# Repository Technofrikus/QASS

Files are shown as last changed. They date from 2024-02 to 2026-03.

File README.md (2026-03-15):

# QASS

QAZ-like for a BAE (Big Ass Enter) and 10u spacebar (7u+8u)

QASS complete

More pictures and infos at [Moinboards](https://moinboards.de/projects/qass/).
[Buildguide](https://moinboards.de/guides/guide-qass/).

There are three versions: normal, lowbar (Miao for FAK-Firmware) and lowbar (Gemini for QMK/Vial). The normal version has the spacebar on the normal PCB. The lowbar uses the PCB as a plate on the bottom row and adds a lower PCB.

- Only the lowbar version was tested and fully finished. Please check the normal version before ordering.
- Lowbar:
  - v1.0 is tested and works with MIAO. XIAO would work as well but the pads on the underside I wanted to use are not GPIOs but only for a special serial protocol. So they cant be used.
  - v1.1 is Untested, but I only made cosmetic changes, so should still work fine.
  - Quark-Works made a fork and changed the MCU to a [Gemini](https://keeb.supply/products/0xcb-gemini) (rp2040 zero compatible). Thanks! You can find it [here](https://github.com/quark-works/QASS-Zero/tree/main).
  - v1.2 Used the fork by Quarks as a basis. Removed a little mistake and made some cosmetic changes.
  - v1.3 the prvious version works, but the silkscreen of the diodes is not visible (orientation of diodes). Corrected this and changed the direction of one diode to be more consistent with the other ones around it.

The latest version has the lower spacebar. Break off the lower part of the PCB and put it under the bottom row. Add headers at the connection points.

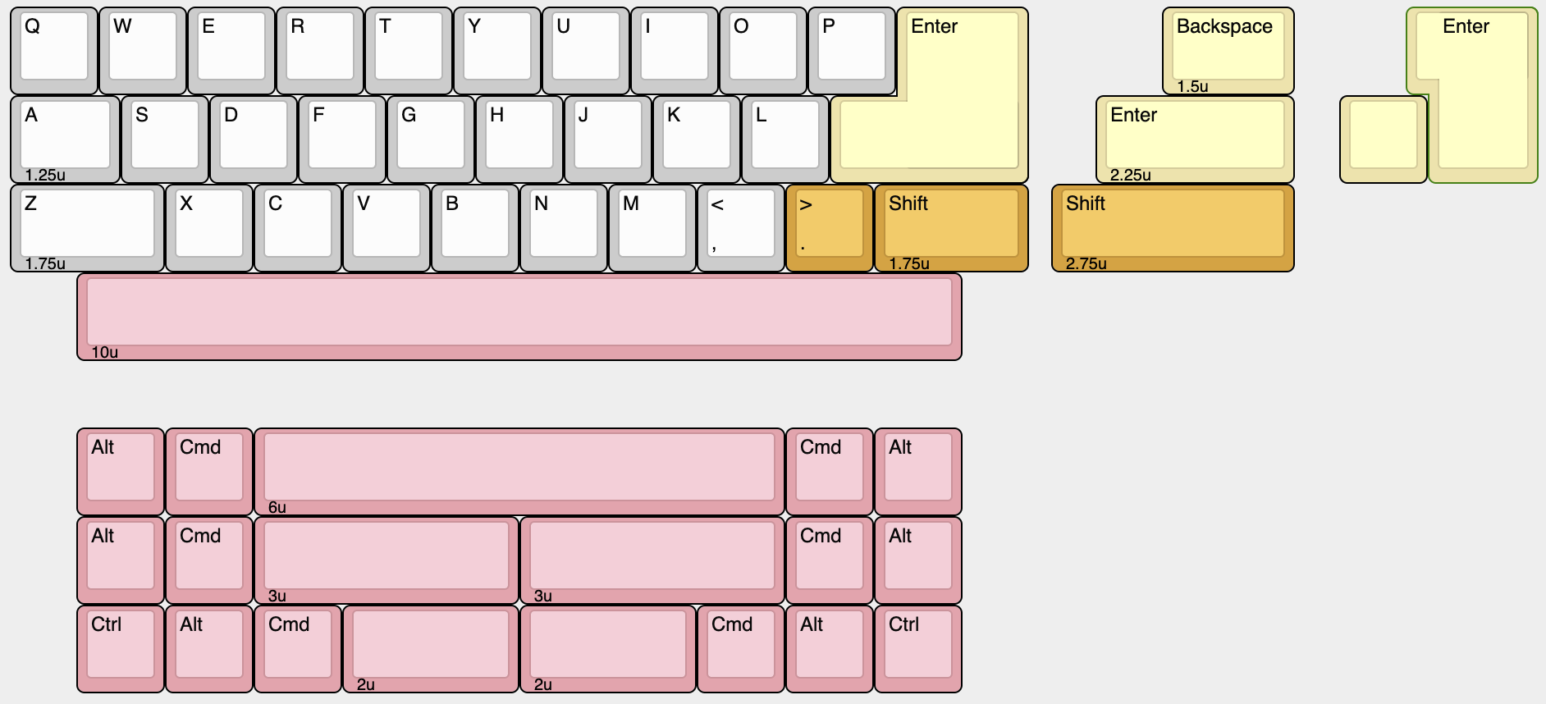
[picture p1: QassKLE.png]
QASS KLE

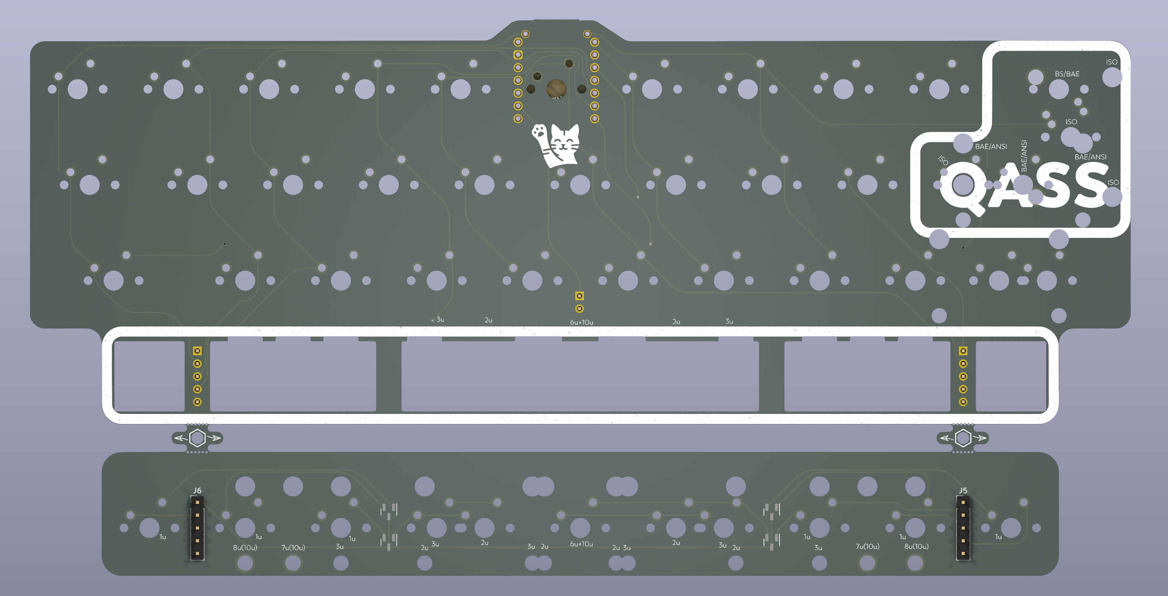
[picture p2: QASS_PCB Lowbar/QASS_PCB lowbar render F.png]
Front of PCB

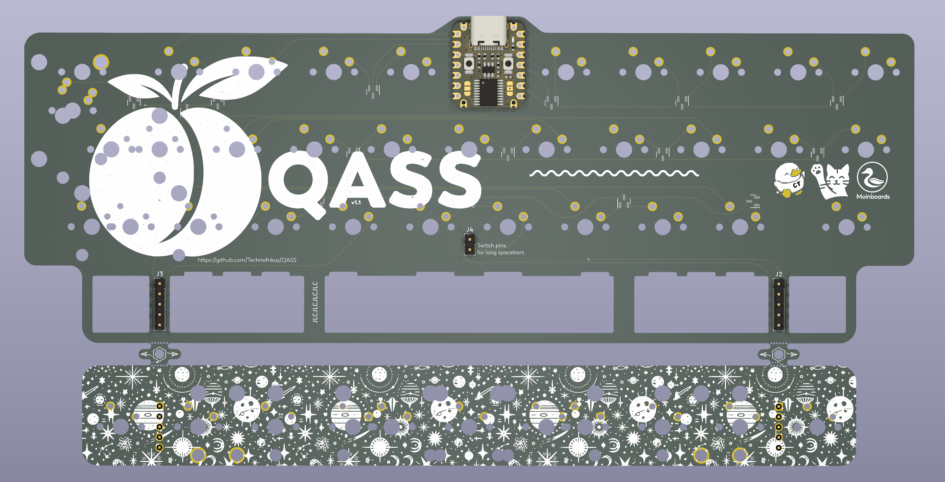
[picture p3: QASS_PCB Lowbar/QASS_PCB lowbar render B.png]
Back of PCB

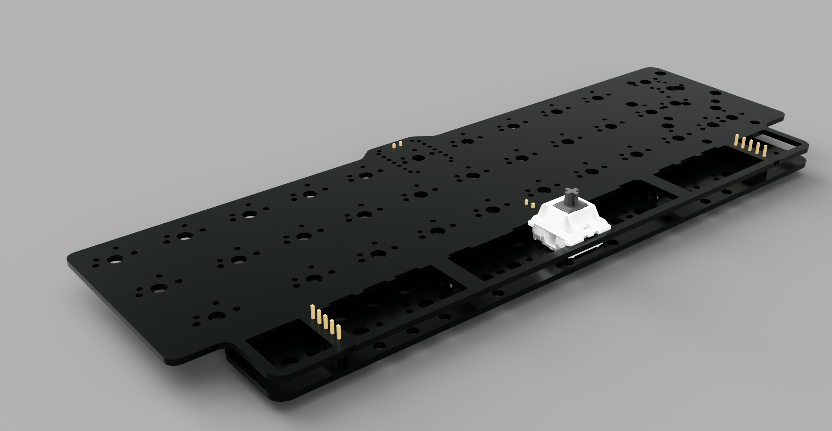
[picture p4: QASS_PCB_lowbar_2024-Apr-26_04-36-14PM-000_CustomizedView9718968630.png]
Lowbar PCB render


## Case

The 3D-printable case files are included now (March 2025).
Can recommend making the plate from metal. Gives the build more weight and looks nice. Tested with brass and copper. Use the special version to make sure they will not warp during cutting (havent tested it without these, just a precaution).
Print recommendations included, see txt file. 

It is for the low-bar version only.

## Firmware
- FAK config and info can be found on [moinboards](https://moinboards.de/guides/guide-qass/#firmware-and-flashing) and here in the firmware folder.
- Vial/Qmk for the fork by Quark. Confirmed working.

## BOM

- [Miao MCU](https://keeb.supply/products/miao) (or [Gemini](https://keeb.supply/products/0xcb-gemini), if you use the Gemini-PCB
- 3mm high hotswap headers (2.54mm pitch) and pins (the holes in the PCB are bigger than usual, so only the plastic part of the headers is on the PCB)
- 20x BAV70 diodes

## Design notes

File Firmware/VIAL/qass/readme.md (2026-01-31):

# qass

qass

*A short description of the keyboard/project*

* Keyboard Maintainer: [Moinboards](https://github.com/technofrikus)
* Hardware Supported: *The PCBs, controllers supported*
* Hardware Availability: *Links to where you can find this hardware*

Make example for this keyboard (after setting up your build environment):

    make qass:default

Flashing example for this keyboard:

    make qass:default:flash

See the [build environment setup](https://docs.qmk.fm/#/getting_started_build_tools) and the [make instructions](https://docs.qmk.fm/#/getting_started_make_guide) for more information. Brand new to QMK? Start with our [Complete Newbs Guide](https://docs.qmk.fm/#/newbs).

## Bootloader

Enter the bootloader in 3 ways:

* **Bootmagic reset**: Hold down the key at (0,0) in the matrix (usually the top left key or Escape) and plug in the keyboard
* **Physical reset button**: Briefly press the button on the back of the PCB - some may have pads you must short instead
* **Keycode in layout**: Press the key mapped to `QK_BOOT` if it is available

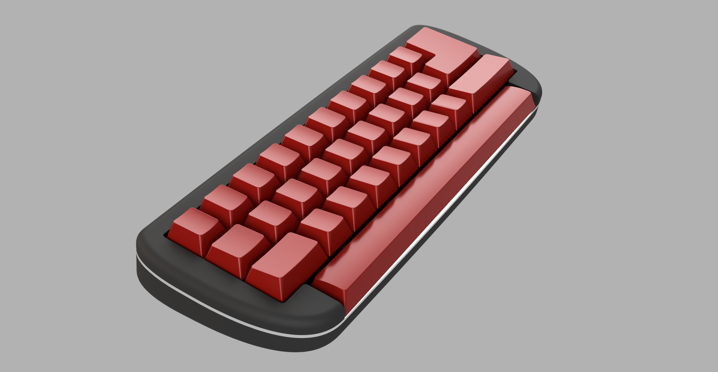
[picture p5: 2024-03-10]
QASS_2024-Mar-06_03-31-12PM-000_CustomizedView2353271758.png

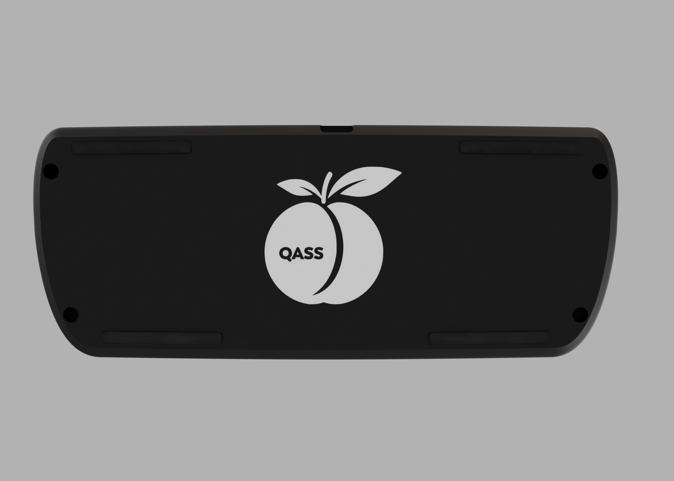
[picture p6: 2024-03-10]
QASS_2024-Mar-04_06-37-35PM-000_CustomizedView2128666624.png

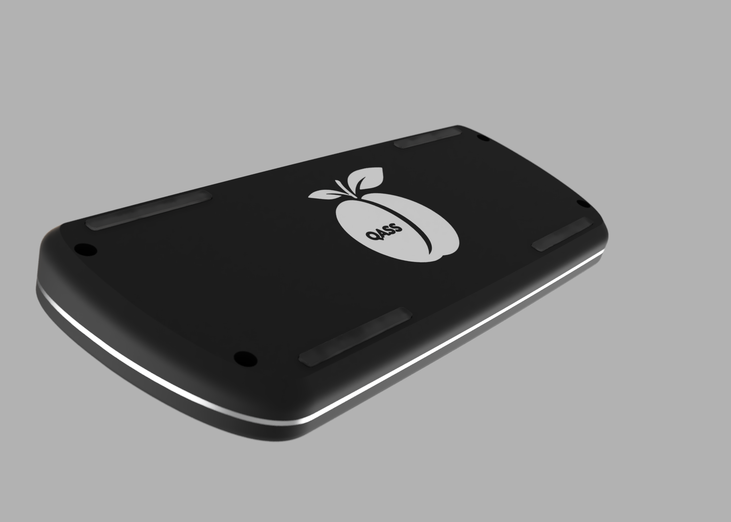
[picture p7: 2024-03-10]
QASS_2024-Mar-04_06-38-51PM-000_CustomizedView16006844155.png

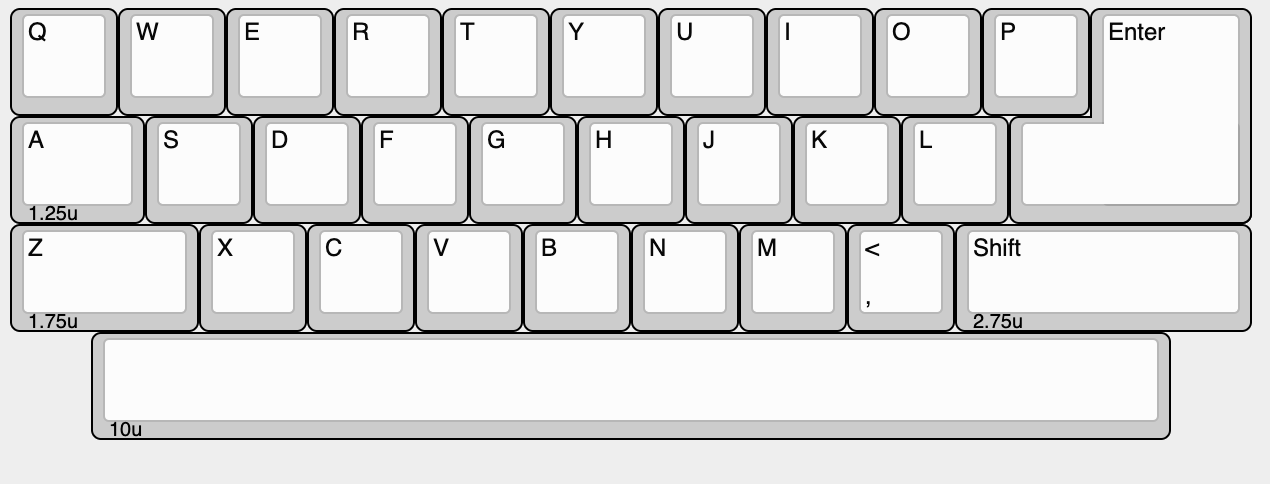
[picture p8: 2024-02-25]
Qass w 2.75 rshift.png

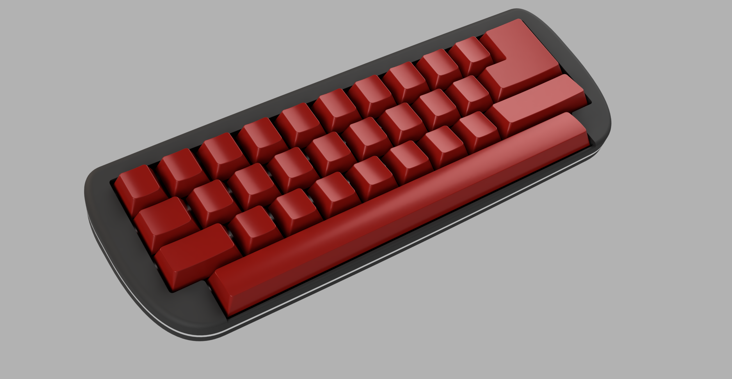
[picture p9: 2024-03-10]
QASS_2024-Mar-05_09-10-02PM-000_CustomizedView11185360985.png

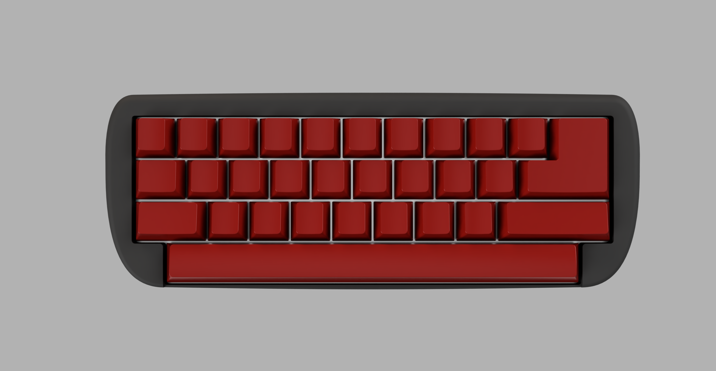
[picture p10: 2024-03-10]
QASS_2024-Mar-05_09-13-01PM-000_CustomizedView4947150229.png

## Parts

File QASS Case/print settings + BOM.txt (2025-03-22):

The stl includes all parts needed. Right click on it and split into parts. Move the plate and upper part away and group the bottom + logo. In OrcaSlicer this is done in the objects tab by marking all parts, right click and assemble.

The 3mf file are my print settings. Not sure if they work on your printer. Otherwise just import the stl.

Use two different colors for the logo and the rest.

I would recommend using variable layer height. The auto settings + smooth work fine. Otherwise the two faces touching the plate have big layer heights and it doesnt look as good.

Supports: bottom yes, other parts no

I use 3 perimeters, but 2 should work as well.

BOM:
- 4x M3x3 threaded insert
- 4x M3x10 srew
- 4x 5x50mm foot

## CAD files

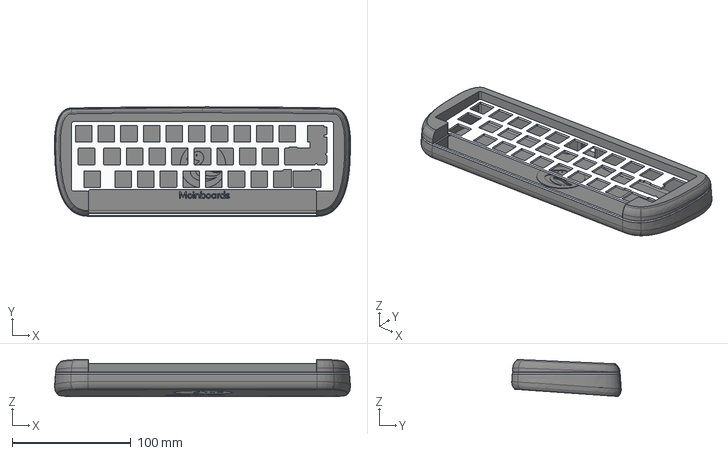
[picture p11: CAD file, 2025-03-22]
QASS Case/Complete case with two-color logo.step
249.2 x 92.2 x 31.2 mm

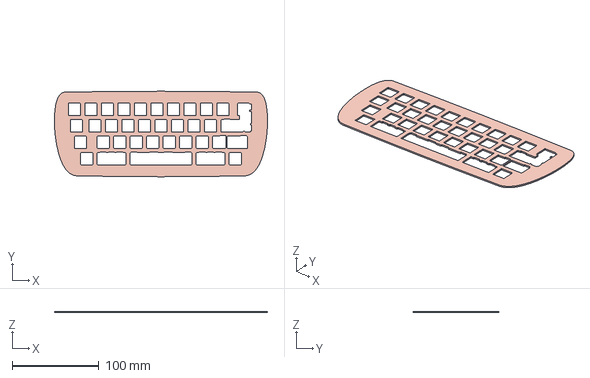
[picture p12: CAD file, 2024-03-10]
Plate.step
245.9 x 98.7 x 1.50 mm

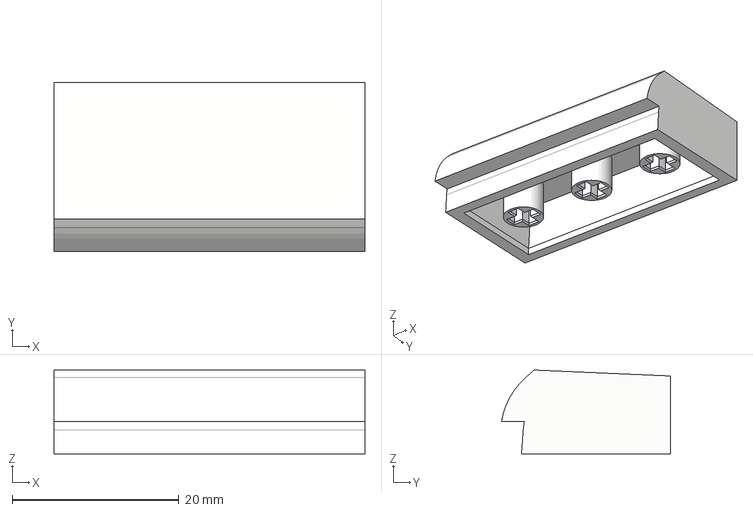
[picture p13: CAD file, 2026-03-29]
QASS Case/Bottom Row 2u.step
37.3 x 20.3 x 10.1 mm

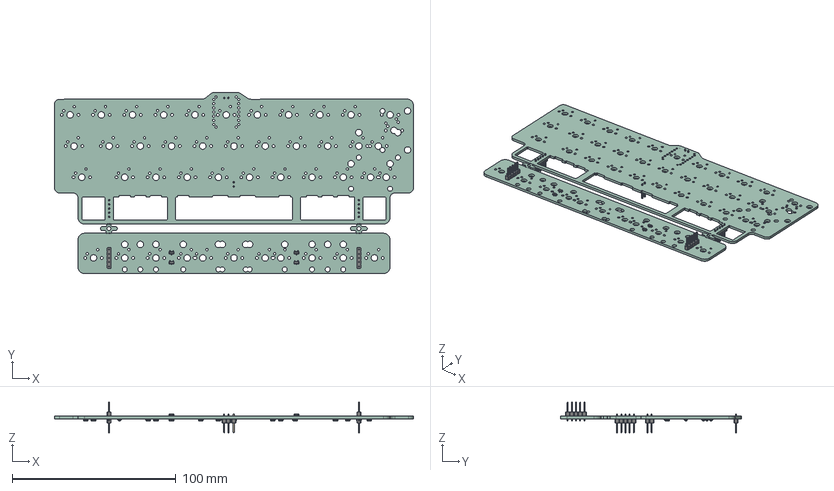
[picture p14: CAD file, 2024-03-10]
QASS_PCB Lowbar/QASS_PCB lowbar.step
219.1 x 110.5 x 18.8 mm
SOT_23 x 20
PinHeader_1x05_P254mm_Vertical x 4
PinHeader_1x02_P254mm_Vertical x 2
QASS_PCB lowbar_PCB

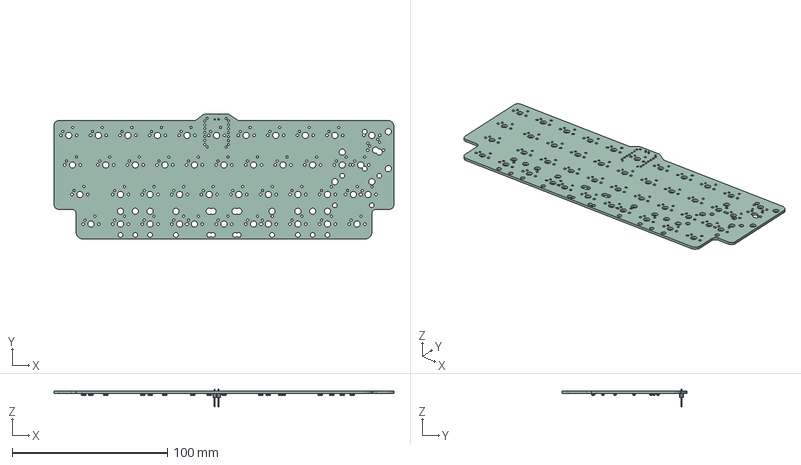
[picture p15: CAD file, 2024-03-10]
QASS_PCB/QASS_PCB.step
219.1 x 80.4 x 11.5 mm
SOT_23 x 20
PinHeader_1x02_P254mm_Vertical
QASS_PCB_PCB

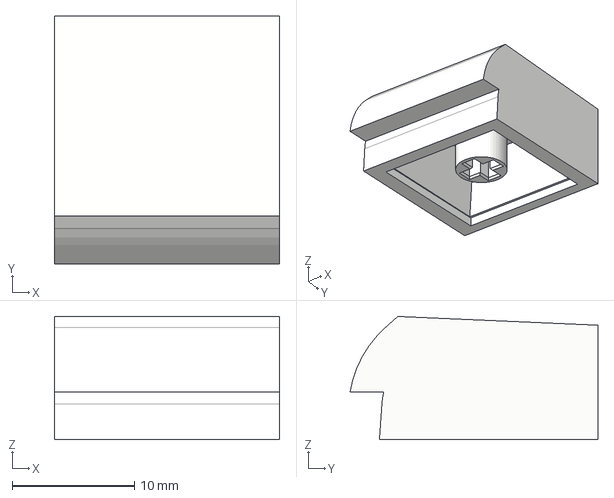
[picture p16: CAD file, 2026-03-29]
QASS Case/Bottom Row 1u.step
18.4 x 20.3 x 10.1 mm

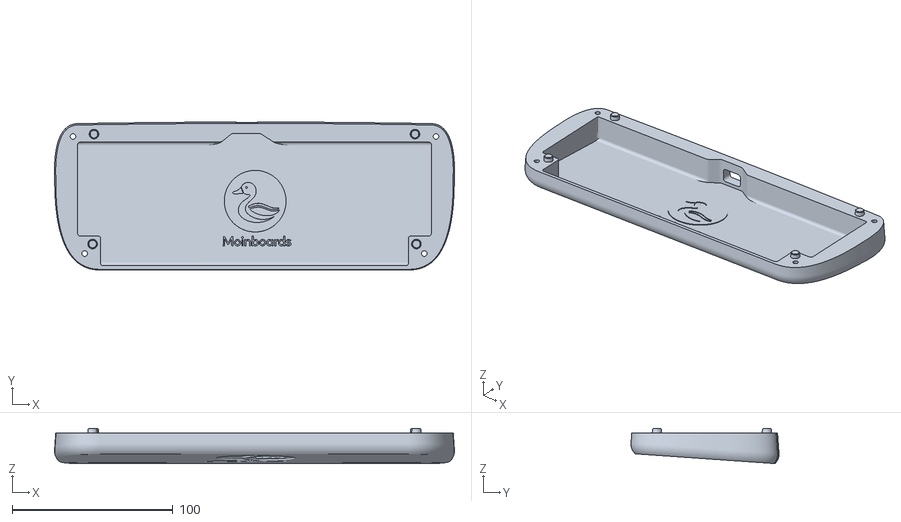
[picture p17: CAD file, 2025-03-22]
QASS Case/Bottom - logo integrated for one color print.stl
249.2 x 92.2 x 21.9

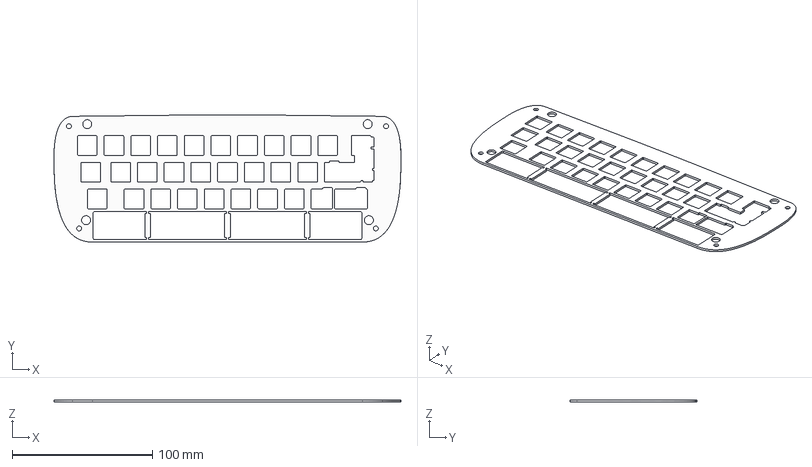
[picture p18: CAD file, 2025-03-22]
QASS Case/Plate lowbar for Metal (remove connectors after cutting).step
247.4 x 90.7 x 1.50 mm

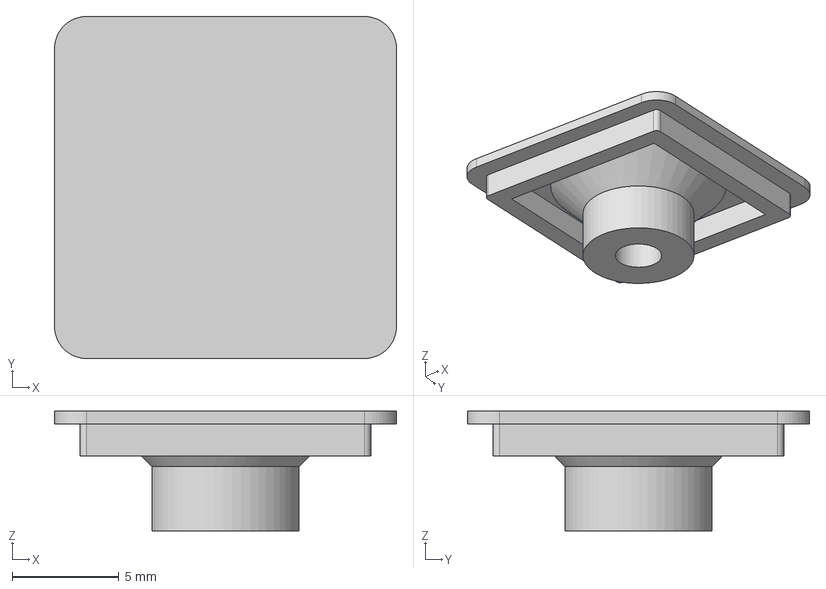
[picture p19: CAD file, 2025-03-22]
QASS Case/Plateholder top part.step
16.0 x 16.0 x 5.60 mm

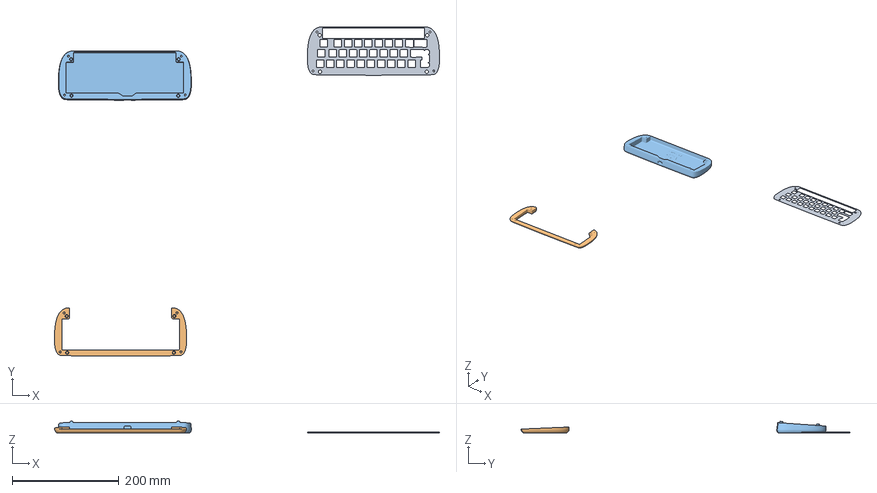
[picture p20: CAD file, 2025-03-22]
QASS Case/qass.3mf
721.3 x 616.9 x 21.7 mm
Gehäuse mit integriertem Space.stl_1
Gehäuse mit integriertem Space.stl_2
Assembly

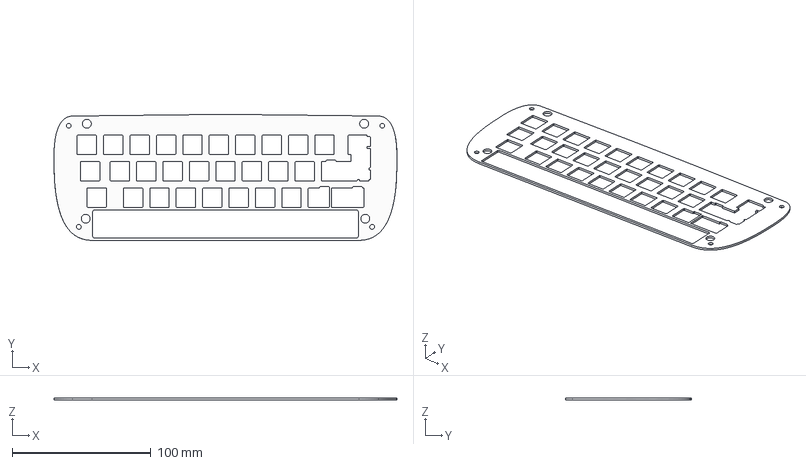
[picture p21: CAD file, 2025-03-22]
QASS Case/Plate lowbar 1.5mm.step
247.4 x 90.7 x 1.50 mm

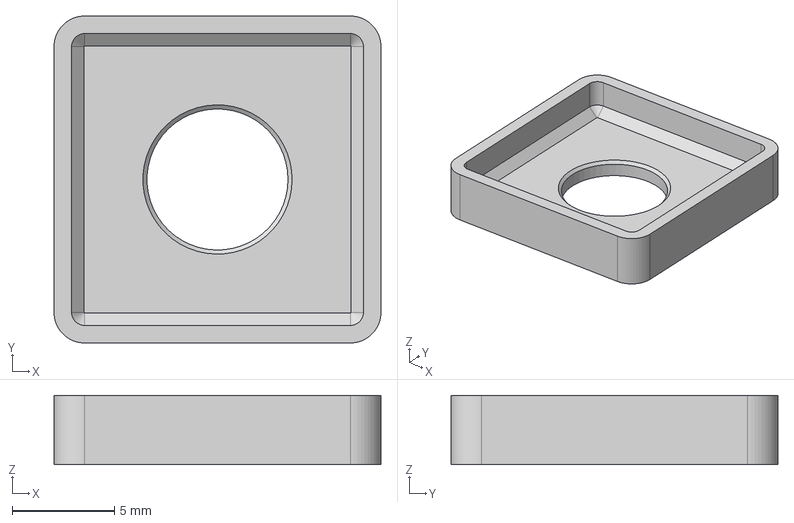
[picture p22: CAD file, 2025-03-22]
QASS Case/Plateholder middle part.step
16.0 x 16.0 x 3.40 mm

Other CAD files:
QASS Case/Complete case with two-color logo.stl

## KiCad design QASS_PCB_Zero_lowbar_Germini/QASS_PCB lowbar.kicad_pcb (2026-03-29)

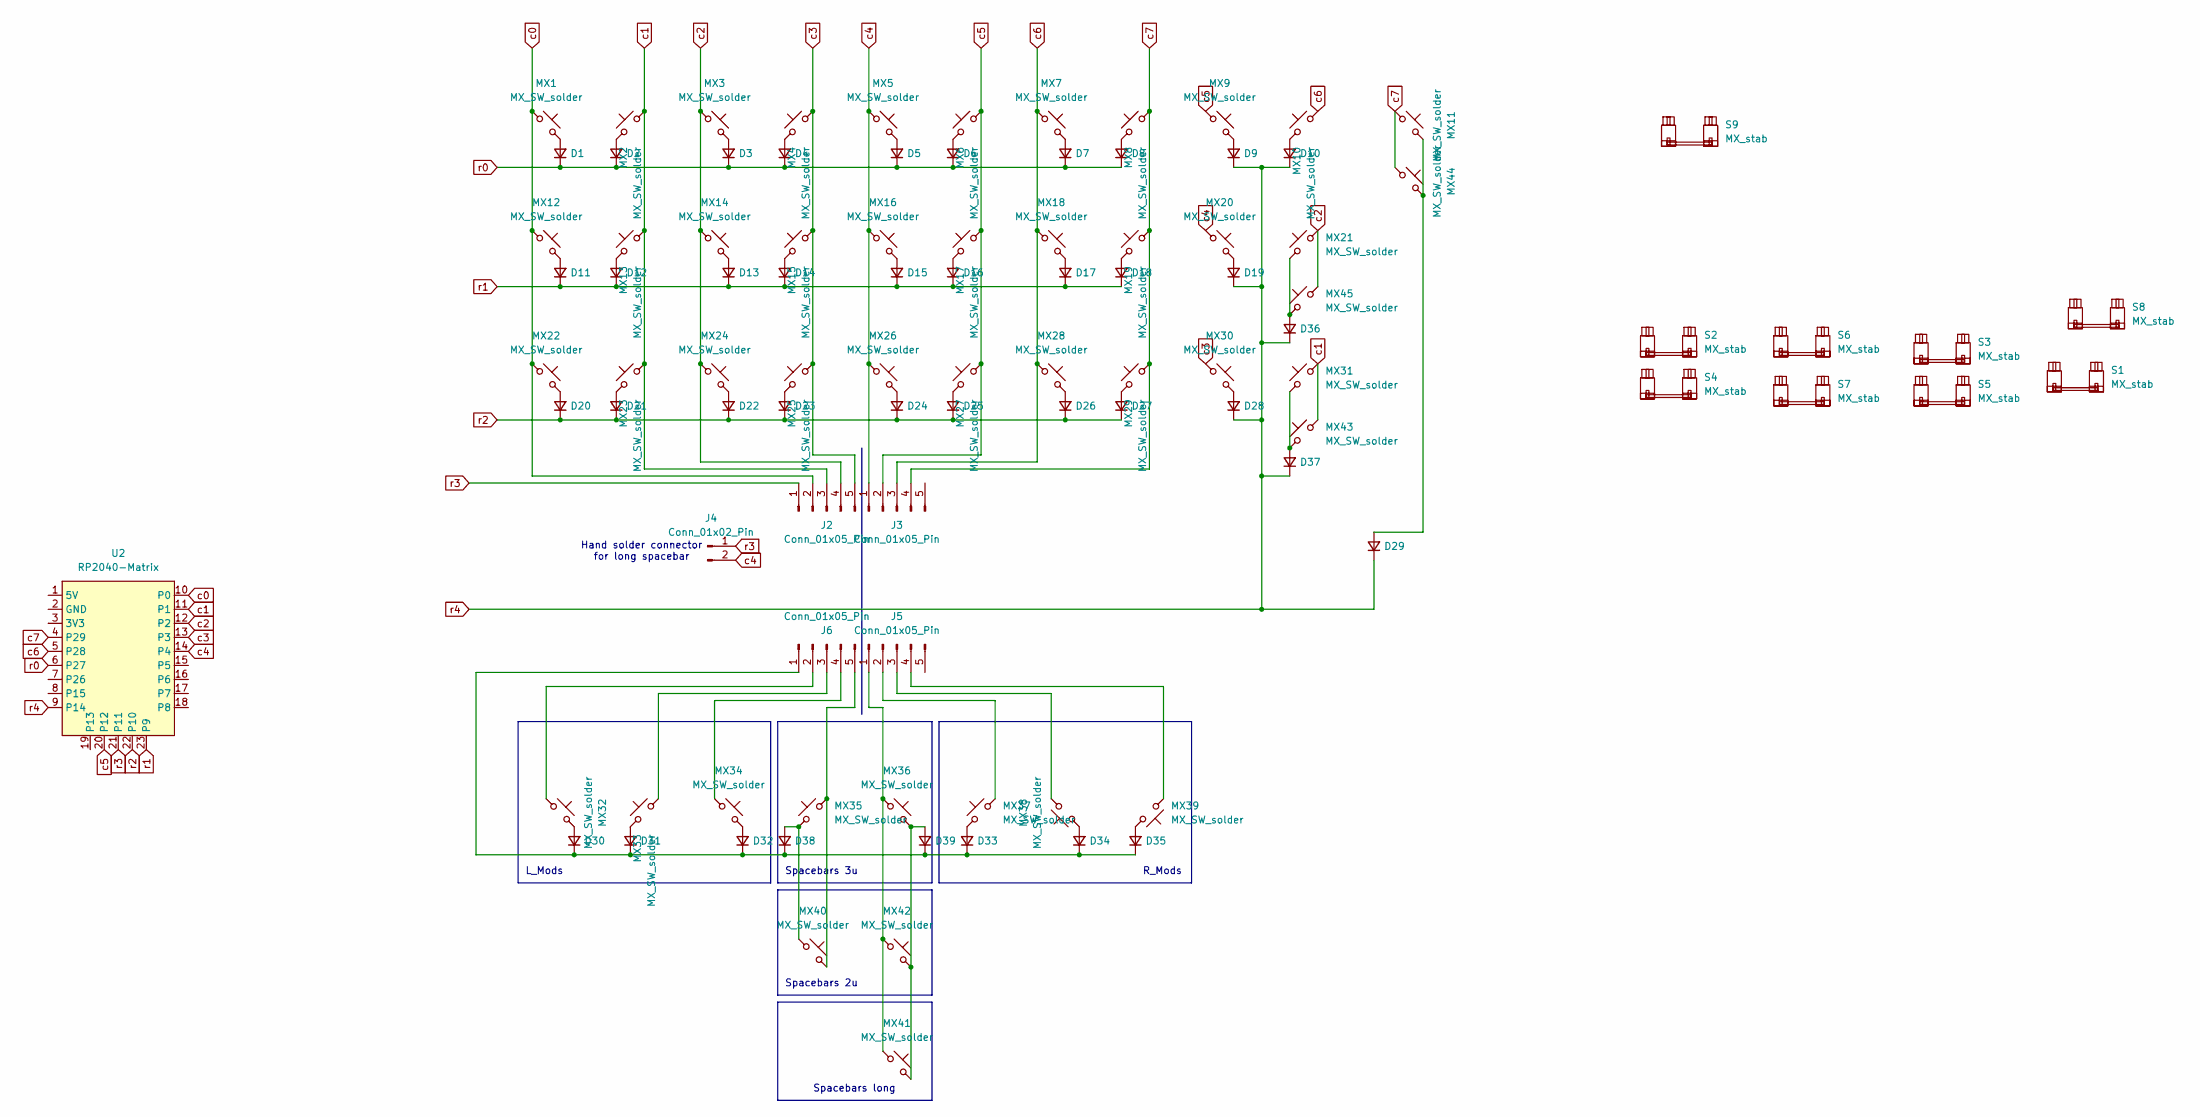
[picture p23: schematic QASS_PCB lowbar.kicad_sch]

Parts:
D1, D2, D3, D4, D5, D6, D7, D8, D9, D10, D11, D12, D13, D14, D15, D16, D17, D18, D19, D20, D21, D22, D23, D24, D25, D26, D27, D28, D29, D30, D31, D32, D33, D34, D35, D36, D37, D38, D39: 1n4148; Diode-dual
J2, J3, J5, J6: Conn_01x05_Pin; PinHeader_1x05_P2.54mm_Vertical
J4: Conn_01x02_Pin; PinHeader_1x02_P2.54mm_Vertical
MX1, MX2, MX3, MX4, MX5, MX6, MX7, MX8, MX9, MX10, MX13, MX14, MX15, MX16, MX17, MX18, MX19, MX20, MX21, MX23, MX24, MX25, MX26, MX27, MX28, MX29, MX30, MX32, MX33, MX34, MX35, MX36, MX37, MX38, MX39, MX40, MX41, MX42, MX43, MX45: MX_SW_solder; SW_MX_1u
MX11, MX44: MX_SW_solder; SW_MX_1.5u
MX12: MX_SW_solder; SW_MX_1.25u
MX22, MX31: MX_SW_solder; SW_MX_1.75u
S1: MX_stab; STAB_MX_2.25u
S2, S3: MX_stab; STAB_MX_3u
S4, S5: MX_stab; STAB_MX_2u
S6: MX_stab; STAB_MX_P_6u
S7: MX_stab; STAB_MX_P_10u
S8: MX_stab; STAB_MX_2.75u
S9: MX_stab; STAB_MX_P_ISO
U2: RP2040-Matrix; RP2040-Matrix_AH

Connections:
unnamed: D1.2 (A), MX1.2
unnamed: D2.2 (A), MX2.2
unnamed: D3.2 (A), MX3.2
unnamed: D4.2 (A), MX4.2
unnamed: D5.2 (A), MX5.2
unnamed: D6.2 (A), MX6.2
unnamed: D7.2 (A), MX7.2
unnamed: D8.2 (A), MX8.2
unnamed: D9.2 (A), MX9.2
unnamed: D10.2 (A), MX10.2
unnamed: D11.2 (A), MX12.2
unnamed: D12.2 (A), MX13.2
unnamed: D13.2 (A), MX14.2
unnamed: D14.2 (A), MX15.2
unnamed: D15.2 (A), MX16.2
unnamed: D16.2 (A), MX17.2
unnamed: D17.2 (A), MX18.2
unnamed: D18.2 (A), MX19.2
unnamed: D19.2 (A), MX20.2
unnamed: D20.2 (A), MX22.2
unnamed: D21.2 (A), MX23.2
unnamed: D22.2 (A), MX24.2
unnamed: D23.2 (A), MX25.2
unnamed: D24.2 (A), MX26.2
unnamed: D25.2 (A), MX27.2
unnamed: D26.2 (A), MX28.2
unnamed: D27.2 (A), MX29.2
unnamed: D28.2 (A), MX30.2
unnamed: D29.2 (A), MX11.1, MX44.1
unnamed: D30.2 (A), MX32.1
unnamed: D30.1 (K), D31.1 (K), D32.1 (K), D33.1 (K), D34.1 (K), D35.1 (K), D38.1 (K), D39.1 (K), J6.1
unnamed: D31.2 (A), MX33.2
unnamed: D32.2 (A), MX34.2
unnamed: D33.2 (A), MX37.1
unnamed: D34.2 (A), MX38.2
unnamed: D35.2 (A), MX39.2
unnamed: D36.2 (A), MX21.1, MX45.1
unnamed: D37.2 (A), MX31.1, MX43.1
unnamed: D38.2 (A), MX35.1, MX40.1
unnamed: D39.2 (A), MX36.2, MX41.2, MX42.2
unnamed: J5.1, MX36.1, MX41.1, MX42.1
unnamed: J5.2, MX37.2
unnamed: J5.3, MX38.1
unnamed: J5.4, MX39.1
unnamed: J6.2, MX32.2
unnamed: J6.3, MX33.1
unnamed: J6.4, MX34.1
unnamed: J6.5, MX35.2, MX40.2
c0: J2.2, MX1.1, MX12.1, MX22.1, U2.10 (P0)
c1: J2.3, MX2.1, MX13.1, MX23.1, MX31.2, MX43.2, U2.11 (P1)
c2: J2.4, MX3.1, MX14.1, MX21.2, MX24.1, MX45.2, U2.12 (P2)
c3: J2.5, MX4.1, MX15.1, MX25.1, MX30.1, U2.13 (P3)
c4: J3.1, J4.2, MX5.1, MX16.1, MX20.1, MX26.1, U2.14 (P4)
c5: J3.2, MX6.1, MX9.1, MX17.1, MX27.1, U2.20 (P12)
c6: J3.3, MX7.1, MX10.1, MX18.1, MX28.1, U2.5 (P28)
c7: J3.4, MX8.1, MX11.2, MX19.1, MX29.1, MX44.2, U2.4 (P29)
r0: D1.1 (K), D2.1 (K), D3.1 (K), D4.1 (K), D5.1 (K), D6.1 (K), D7.1 (K), D8.1 (K), U2.6 (P27)
r1: D11.1 (K), D12.1 (K), D13.1 (K), D14.1 (K), D15.1 (K), D16.1 (K), D17.1 (K), D18.1 (K), U2.23 (P9)
r2: D20.1 (K), D21.1 (K), D22.1 (K), D23.1 (K), D24.1 (K), D25.1 (K), D26.1 (K), D27.1 (K), U2.22 (P10)
r3: J2.1, J4.1, U2.21 (P11)
r4: D9.1 (K), D10.1 (K), D19.1 (K), D28.1 (K), D29.1 (K), D36.1 (K), D37.1 (K), U2.9 (P14)

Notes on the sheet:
Hand solder connector for long spacebar
L_Mods
R_Mods
Spacebars 2u
Spacebars 3u
Spacebars long

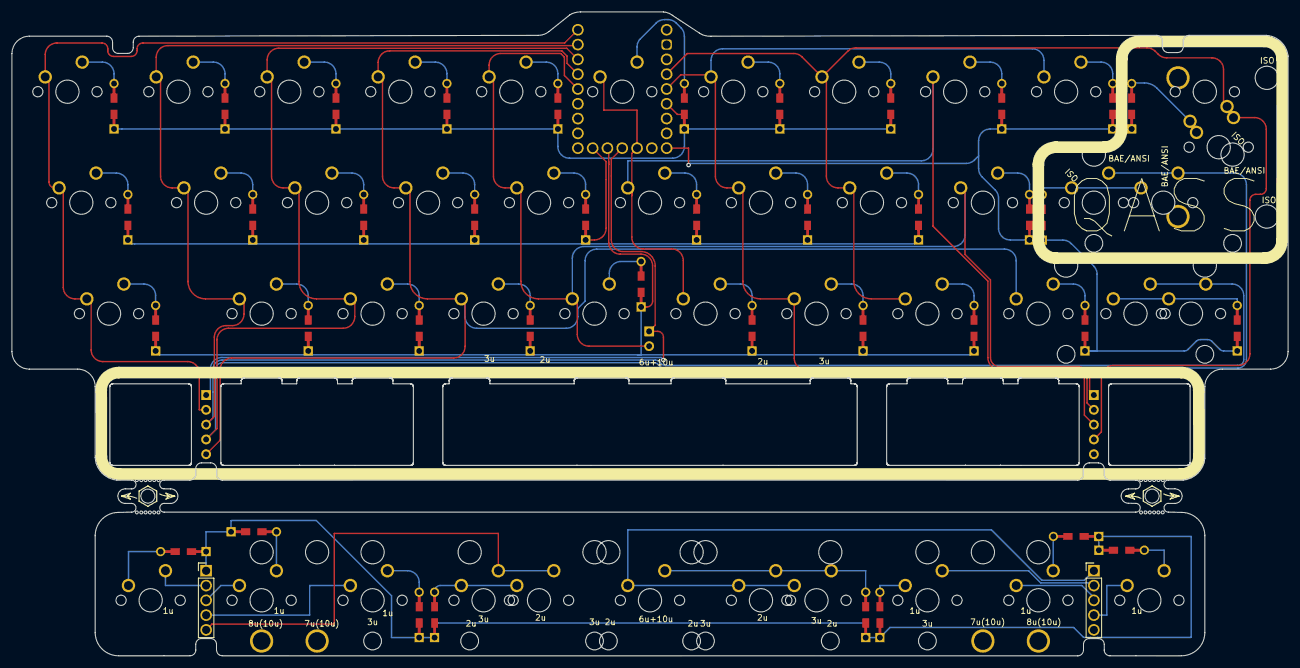
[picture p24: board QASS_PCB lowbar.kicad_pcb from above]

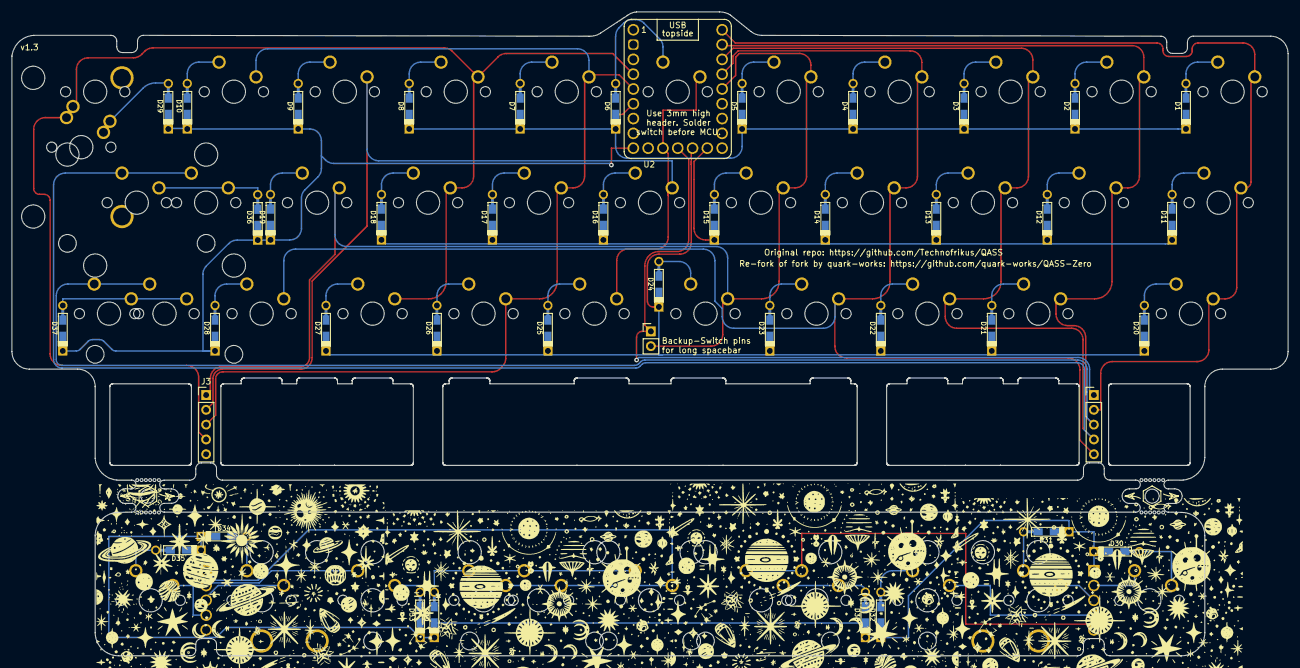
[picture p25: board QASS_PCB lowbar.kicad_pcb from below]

Board: 2 copper layers, 219.1 x 110.5 mm, 104 parts (47 on the bottom side), 61 nets.

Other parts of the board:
MB5, MB5#2: 5.5mm; mousebites_5p5mm_easysnap
Ref**: Val**; starpattern
Ref**#2, Ref**#3, Ref**#4: Val**; starpattern

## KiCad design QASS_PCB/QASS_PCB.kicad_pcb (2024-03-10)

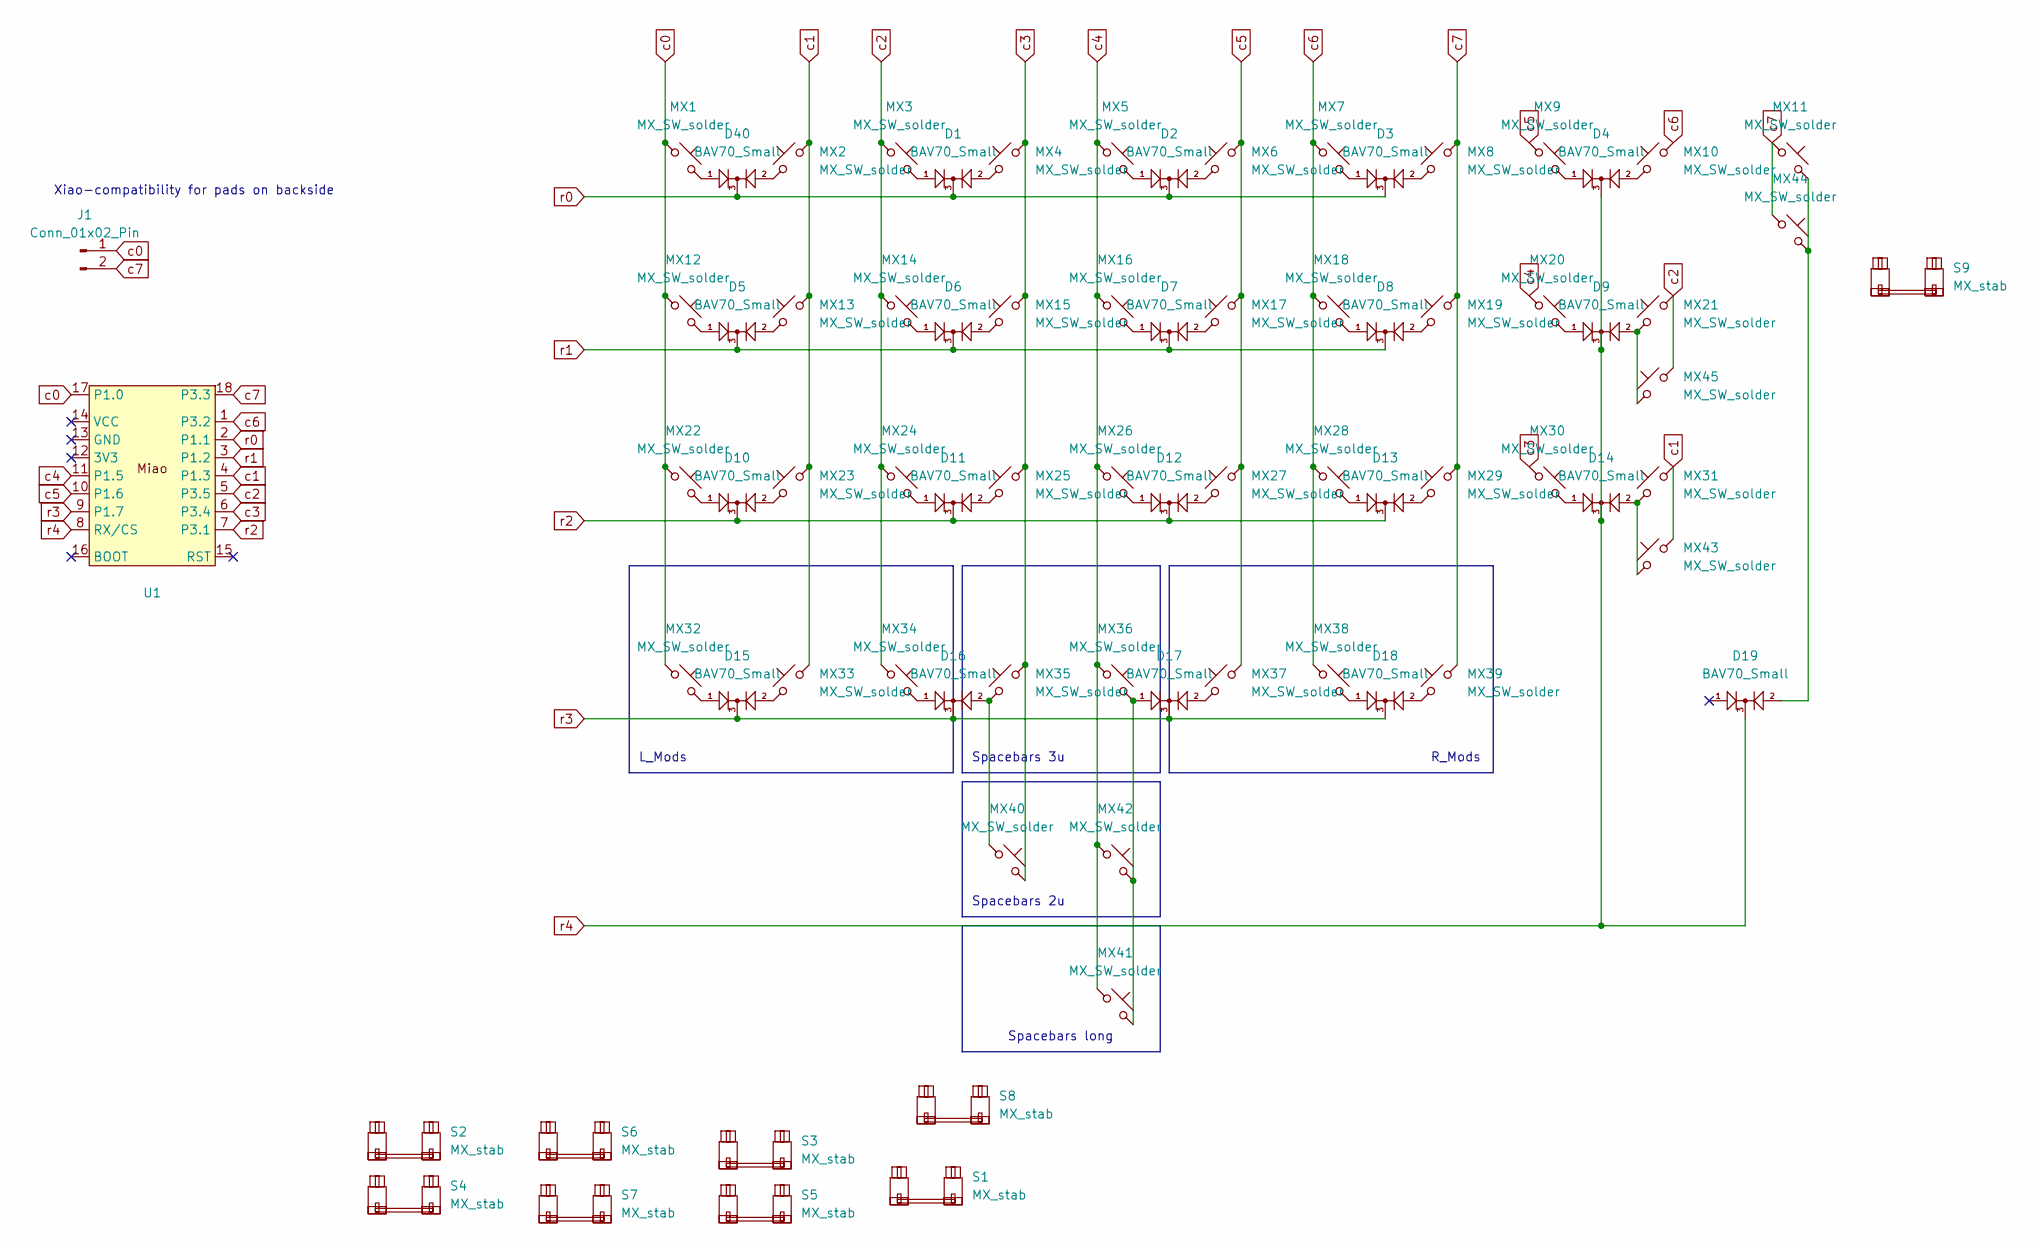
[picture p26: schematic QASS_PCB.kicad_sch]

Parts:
D1, D2, D3, D4, D5, D6, D7, D8, D9, D10, D11, D12, D13, D14, D15, D16, D17, D18, D19, D40: BAV70_Small; SOT-23
J1: Conn_01x02_Pin; PinHeader_1x02_P2.54mm_Vertical
MX1, MX2, MX3, MX4, MX5, MX6, MX7, MX8, MX9, MX10, MX13, MX14, MX15, MX16, MX17, MX18, MX19, MX20, MX21, MX23, MX24, MX25, MX26, MX27, MX28, MX29, MX30, MX32, MX33, MX34, MX35, MX36, MX37, MX38, MX39, MX40, MX41, MX42, MX43, MX45: MX_SW_solder; SW_MX_1u
MX11, MX44: MX_SW_solder; SW_MX_1.5u
MX12: MX_SW_solder; SW_MX_1.25u
MX22, MX31: MX_SW_solder; SW_MX_1.75u
S1: MX_stab; STAB_MX_2.25u
S2, S3: MX_stab; STAB_MX_3u
S4, S5: MX_stab; STAB_MX_2u
S6: MX_stab; STAB_MX_P_6u
S7: MX_stab; STAB_MX_P_10u
S8: MX_stab; STAB_MX_2.75u
S9: MX_stab; STAB_MX_P_ISO
U1: Miao

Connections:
unnamed: D1.1 (A1), MX3.2
unnamed: D1.2 (A2), MX4.1
unnamed: D2.1 (A1), MX5.2
unnamed: D2.2 (A2), MX6.1
unnamed: D3.1 (A1), MX7.2
unnamed: D3.2 (A2), MX8.1
unnamed: D4.1 (A1), MX9.2
unnamed: D4.2 (A2), MX10.1
unnamed: D5.1 (A1), MX12.2
unnamed: D5.2 (A2), MX13.1
unnamed: D6.1 (A1), MX14.2
unnamed: D6.2 (A2), MX15.1
unnamed: D7.1 (A1), MX16.2
unnamed: D7.2 (A2), MX17.1
unnamed: D8.1 (A1), MX18.2
unnamed: D8.2 (A2), MX19.1
unnamed: D9.1 (A1), MX20.2
unnamed: D9.2 (A2), MX21.1, MX45.1
unnamed: D10.1 (A1), MX22.2
unnamed: D10.2 (A2), MX23.1
unnamed: D11.1 (A1), MX24.2
unnamed: D11.2 (A2), MX25.1
unnamed: D12.1 (A1), MX26.2
unnamed: D12.2 (A2), MX27.1
unnamed: D13.1 (A1), MX28.2
unnamed: D13.2 (A2), MX29.1
unnamed: D14.1 (A1), MX30.2
unnamed: D14.2 (A2), MX31.1, MX43.1
unnamed: D15.1 (A1), MX32.2
unnamed: D15.2 (A2), MX33.1
unnamed: D16.1 (A1), MX34.2
unnamed: D16.2 (A2), MX35.1, MX40.1
unnamed: D17.1 (A1), MX36.2, MX41.2, MX42.2
unnamed: D17.2 (A2), MX37.1
unnamed: D18.1 (A1), MX38.2
unnamed: D18.2 (A2), MX39.1
unnamed: D19.2 (A2), MX11.2, MX44.2
unnamed: D40.1 (A1), MX1.2
unnamed: D40.2 (A2), MX2.1
c0: J1.1, MX1.1, MX12.1, MX22.1, MX32.1, U1.17 (P1.0)
c1: MX2.2, MX13.2, MX23.2, MX31.2, MX33.2, MX43.2, U1.4 (P1.3)
c2: MX3.1, MX14.1, MX21.2, MX24.1, MX34.1, MX45.2, U1.5 (P3.5)
c3: MX4.2, MX15.2, MX25.2, MX30.1, MX35.2, MX40.2, U1.6 (P3.4)
c4: MX5.1, MX16.1, MX20.1, MX26.1, MX36.1, MX41.1, MX42.1, U1.11 (P1.5)
c5: MX6.2, MX9.1, MX17.2, MX27.2, MX37.2, U1.10 (P1.6)
c6: MX7.1, MX10.2, MX18.1, MX28.1, MX38.1, U1.1 (P3.2)
c7: J1.2, MX8.2, MX11.1, MX19.2, MX29.2, MX39.2, MX44.1, U1.18 (P3.3)
r0: D1.3 (K), D2.3 (K), D3.3 (K), D40.3 (K), U1.2 (P1.1)
r1: D5.3 (K), D6.3 (K), D7.3 (K), D8.3 (K), U1.3 (P1.2)
r2: D10.3 (K), D11.3 (K), D12.3 (K), D13.3 (K), U1.7 (P3.1)
r3: D15.3 (K), D16.3 (K), D17.3 (K), D18.3 (K), U1.9 (P1.7)
r4: D4.3 (K), D9.3 (K), D14.3 (K), D19.3 (K), U1.8 (RX/CS)

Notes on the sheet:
L_Mods
R_Mods
Spacebars 2u
Xiao-compatibility for pads on backside
Spacebars 3u
Spacebars long

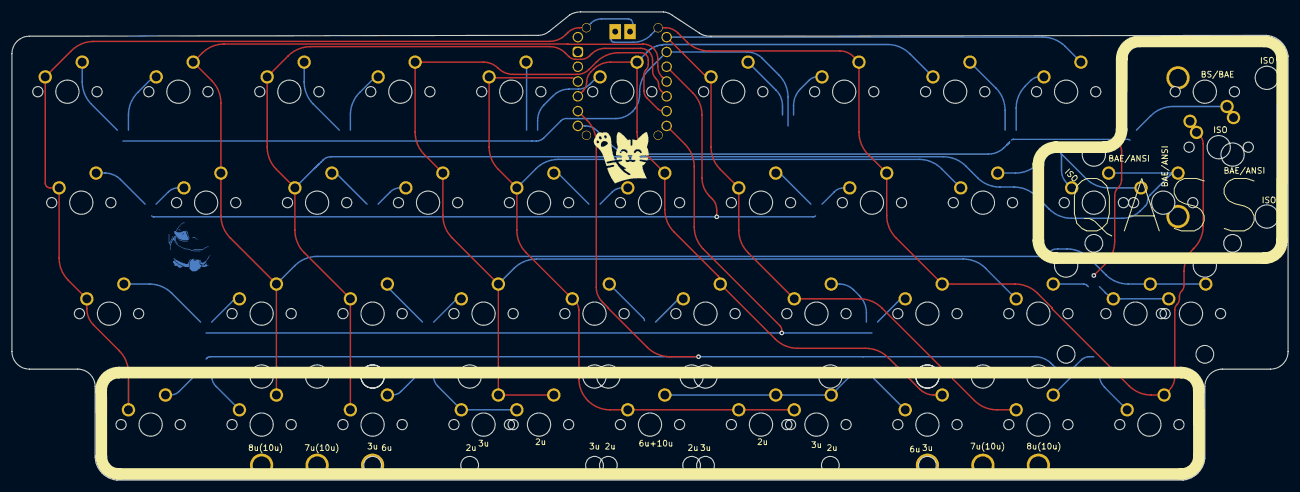
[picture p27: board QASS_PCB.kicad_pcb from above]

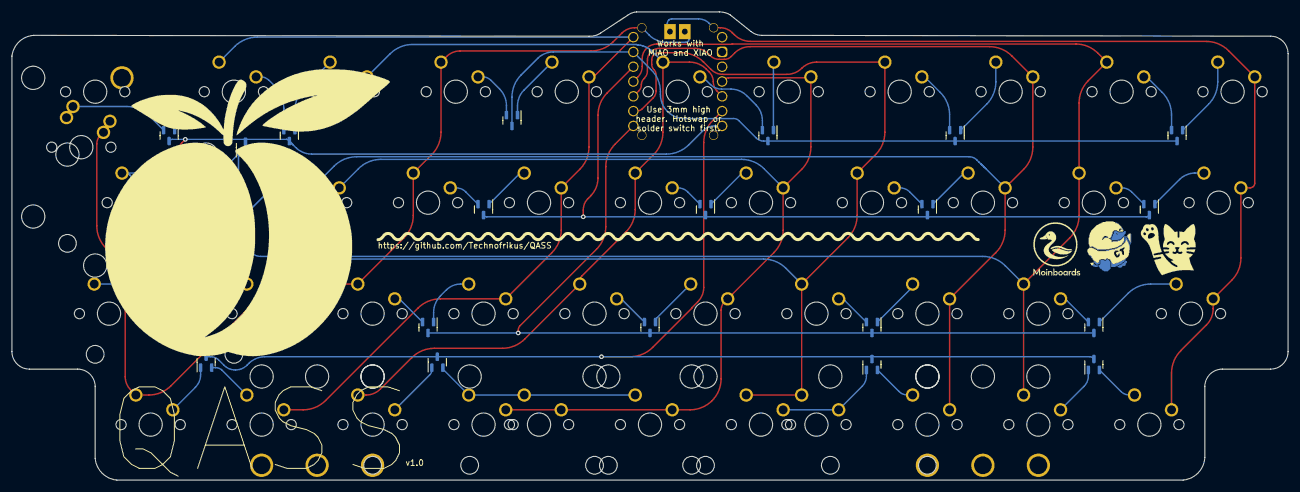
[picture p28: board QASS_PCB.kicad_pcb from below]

Board: 2 copper layers, 219.1 x 80.4 mm, 80 parts (25 on the bottom side), 52 nets.

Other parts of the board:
Ref**: Val**; Miaoxiao 10mm
Ref**#2: Val**; Miaoxiao 10mm
Ref**#3: Val**; Duck 2 with text
Ref**#4: Val**; peach simple qass logo

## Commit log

2024-02-21 Erster Runde
    [QASS_PCB.kicad_pcb, QASS_PCB.kicad_sch]
2024-02-24 working on it
    [QASS_PCB.kicad_pcb, QASS_PCB.kicad_sch]
2024-02-24 Routing down, pretty close to final
    [QASS_PCB.kicad_pcb, QASS_PCB.kicad_sch]
2024-02-25 Step exported
    [QASS_PCB.kicad_pcb, QASS_PCB.step]
2024-02-25 Added 2.75u right shift option
    [QASS_PCB-B_Cu.gbr, QASS_PCB-B_Mask.gbr, QASS_PCB-B_Paste.gbr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]
2024-02-29 Added ISO Enter
    [QASS_PCB.kicad_pcb, QASS_PCB.kicad_sch]
2024-03-10 Second version added: lowbar
    [Plate.step, QASS_PCB lowbar.kicad_sch, QASS_PCB lowbar.step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]
2024-03-16 v1.0, protoype ordered
    [QASS_PCB lowbar.kicad_sch]
2024-05-03 v1.1 - [x] Beschriftung der Switches in der BottomRow auf Oberem PCB - [x] Doppelten 6+3u stab entfert - [x] Switchpositionen auf unterem PCB auch markiert - [x] Unteren zwei Löcher für MCU weggelass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
    [QASS_PCB lowbar.kicad_sch]
2024-05-03 Added renders of lowbar PCB
2025-03-22 Added Case
    [Bottom - logo integrated for one color print.stl, Complete case with two-color logo.step, Complete case with two-color logo.stl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]
2025-03-28 Added Link to the fork of the PCB with Gemini MCU
2025-03-28 Added the fork of the PCB with Gemini MCU
2026-01-31 Used the fork by Quarks to make my own Gemini-Version of the PCB. A small mistake was fixed and some asthetic changes made.
    [QASS_PCB lowbar.kicad_sch]
2026-03-01 PCB lowbar for Gemini finished. Ordered. Untested yet.
    [QASS_PCB lowbar.kicad_pcb]
2026-03-15 v1.3 - silkscreen better and one diode orientation more consistent
    [QASS_PCB lowbar.kicad_pcb, QASS_PCB lowbar.kicad_sch]
2026-03-15 correct version number in Silk
    [QASS_PCB lowbar.kicad_pcb]
2026-03-29 Added Custom Bottom Row Keys for printing
    [Bottom Row 1u.step, Bottom Row 2u.step, QASS_PCB lowbar.kicad_pcb]
